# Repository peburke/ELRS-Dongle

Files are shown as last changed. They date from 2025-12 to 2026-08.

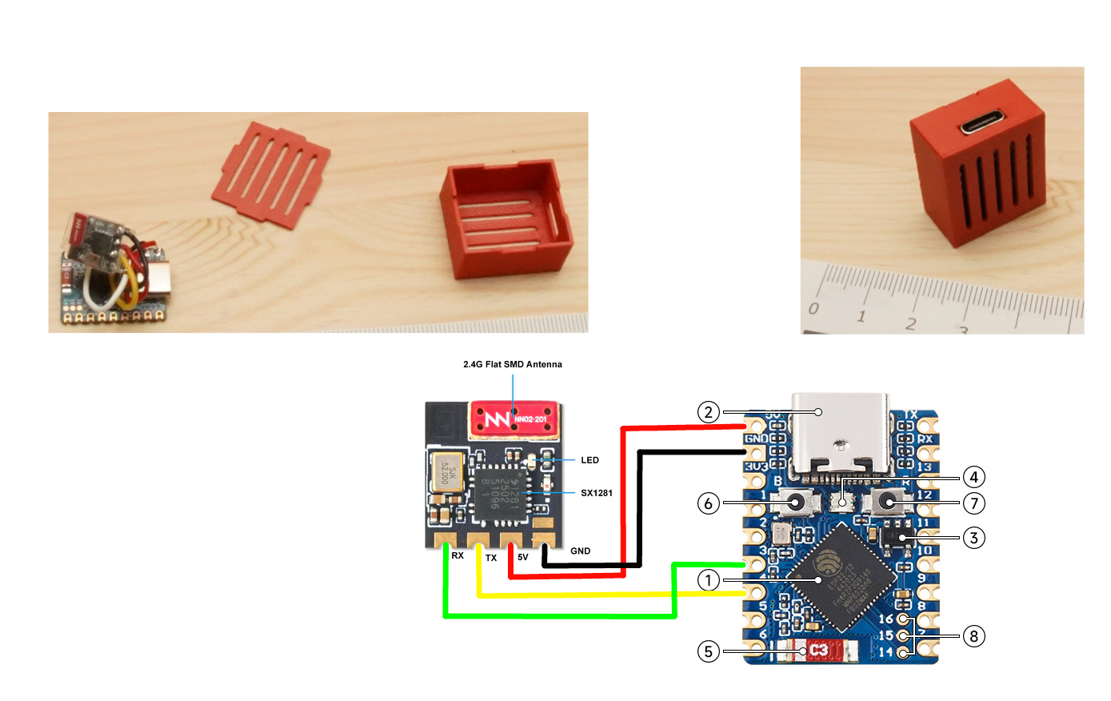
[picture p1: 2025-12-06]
Dongle.jpg

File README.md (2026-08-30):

# ELRS Dongle

An inexpensive wireless USB gamepad adapter for FPV simulators. It connects an
EdgeTX radio through an ExpressLRS transmitter and receiver to an ESP32-S3,
which presents the first four CRSF channels to a PC as joystick axes.

The dongle has been tested with Velocidrone and Liftoff. The hardware uses an
ESP32-S3-Mini and a BetaFPV ELRS Lite receiver; printable enclosure files are
included in this repository.

ELRS Dongle

See [Firmware.md](Firmware.md) for wiring, Arduino settings, calibration,
failsafe behavior, testing, and troubleshooting.

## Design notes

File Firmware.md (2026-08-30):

# ELRS Dongle Firmware

The firmware converts CRSF RC data from an ExpressLRS receiver into a native
USB HID gamepad on an ESP32-S3.

## Repository layout

| Path | Purpose |
|---|---|
| `ELRS_Dongle.ino` | ESP32-S3 hardware setup and main loop. |
| `ELRSProtocol.h/.cpp` | Testable CRSF parser, channel decoder, scaling, and failsafe state. |
| `tests/test_elrs_protocol.cpp` | Host-side protocol and behavior regression tests. |
| `.github/workflows/firmware.yml` | Native tests and an ESP32 Arduino 3.3.4 build. |
| `Body.stl`, `Top.stl`, `Dongle Case-*.3mf` | Printable enclosure files. |

## Data flow

1. UART1 reads the receiver at 420000 baud.
2. `CrsfParser` collects a frame, rejects invalid lengths and CRCs, and resets
   a stalled partial frame after 2 ms.
3. Valid type `0x16` payloads are unpacked into sixteen 11-bit channels.
4. Channels 1-4 become X, Y, throttle/Z, and Rz USB axes.
5. If no valid RC frame arrives for 1000 ms after the link has been active, a
   safe report centers roll, pitch, and yaw and lowers throttle. A rejected USB
   send is retried every 20 ms until delivery succeeds.

## Wiring

| Receiver signal | ESP32-S3 | Notes |
|---|---|---|
| TX | GPIO 3 | Required CRSF data connection. |
| RX | GPIO 4 | Reserved for future telemetry; currently unused. |
| Power and ground | Board-appropriate supply and GND | Verify the receiver voltage before wiring. |

Change `kCrsfRxPin` and `kCrsfTxPin` in `ELRS_Dongle.ino` for a different
board layout.

## Arduino configuration

- Install ESP32 Arduino core 3.3.4.
- Select an ESP32-S3 board with native USB.
- Set **USB Mode** to **USB-OTG (TinyUSB)**. `ARDUINO_USB_MODE=0` is the
  TinyUSB/OTG mode used by `USBHIDGamepad`; Hardware CDC and JTAG mode cannot
  provide this HID interface.
- Compile and upload `ELRS_Dongle.ino` together with `ELRSProtocol.h` and
  `ELRSProtocol.cpp` in a folder named `ELRS_Dongle`.

The sketch deliberately stops at compile time when native USB is unavailable
or the incompatible hardware CDC/JTAG mode is selected.

## USB controls and calibration

| CRSF channel | HID control |
|---|---|
| CH1 | X / roll |
| CH2 | Y / pitch |
| CH3 | Z / throttle |
| CH4 | Rz / yaw |

The CRSF calibration constants are minimum `172`, center `992`, and maximum
`1811`. Directional axes are scaled separately below and above center so that
center is exactly zero and both endpoints reach the HID range. Throttle maps
minimum to `-127` and maximum to `127`. Inputs outside the calibrated range
are clamped.

The unused hat is sent as `HAT_CENTER` (`0` in ESP32 core 3.3.4), and unused
buttons and axes remain released/centered.

## Link-loss behavior

CRSF receivers can stop transmitting RC channel frames during failsafe. The
firmware records each valid CRC-checked RC frame. Once a working stream has
been seen, a 1000 ms gap requests a safe USB report with centered directional
axes, minimum throttle, centered hat, and no buttons. Delivery is confirmed
only when the HID API accepts the report; a temporarily busy USB interface is
retried every 20 ms. A later valid frame automatically resumes normal reports
and rearms the timeout.

Change `kRcFailsafeTimeoutMs` if a different delay is required. Do not set it
below the expected radio update interval.

## Tests

On Windows with `g++` available:

```powershell
./tests/run_tests.ps1
```

The suite checks a hand-derived packed-channel fixture, CRC rejection,
calibrated axis endpoints, neutral HID state, one-shot link failsafe, and
parser recovery after an inter-byte timeout. GitHub Actions runs the same
tests and compiles the sketch for ESP32-S3 against core 3.3.4.

## Troubleshooting

- **No USB gamepad:** confirm the cable carries data and USB Mode is USB-OTG,
  then check that the native USB connector is being used.
- **No axis movement:** confirm the receiver is bound, set to CRSF output, and
  its TX pad is connected to GPIO 3 with a common ground.
- **Axes reversed:** reverse the corresponding transmitter output or negate
  that axis when constructing the HID report.
- **Reduced travel:** first verify transmitter output limits, then calibrate
  the controller in the simulator.

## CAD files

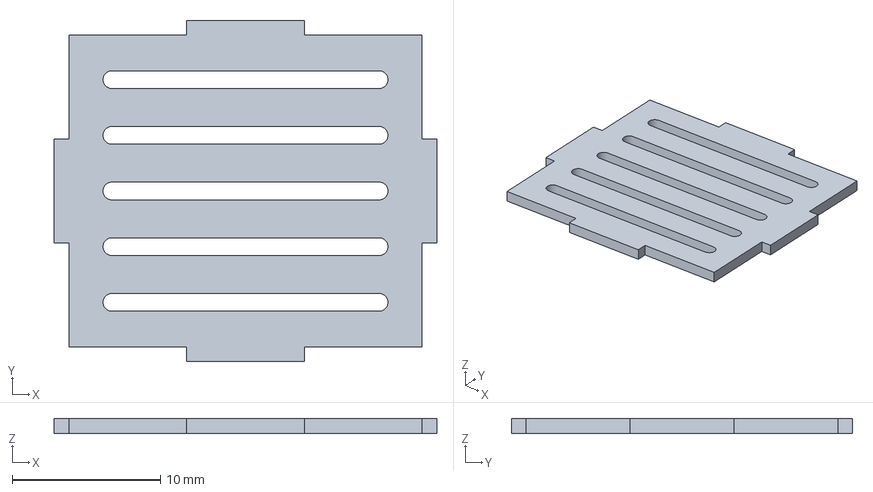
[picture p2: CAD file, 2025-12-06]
Dongle Case-Top.3mf
25.8 x 23.0 x 1.00 mm

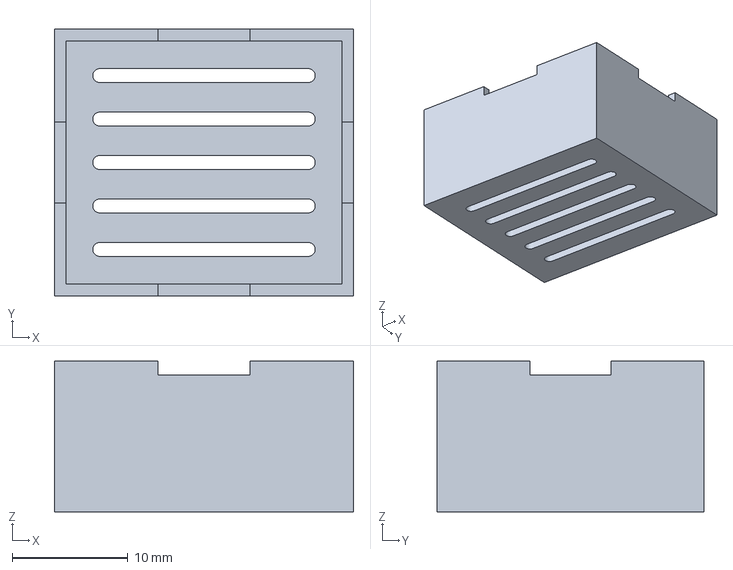
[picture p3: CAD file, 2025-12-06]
Dongle Case-Body.3mf
25.8 x 23.0 x 13.0 mm

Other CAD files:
Top.stl
Body.stl

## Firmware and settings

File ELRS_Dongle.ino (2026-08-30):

/*
 * CRSF to USB HID gamepad bridge for ESP32-S3.
 *
 * Connect the ELRS receiver TX pad to GPIO 3. GPIO 4 is reserved for
 * future CRSF telemetry and is not used by this receive-only firmware.
 */

#include <Arduino.h>

#ifndef ARDUINO_USB_MODE
#error "This firmware requires an ESP32 with native USB support."
#elif ARDUINO_USB_MODE == 1
#error "Select USB-OTG (TinyUSB), not Hardware CDC and JTAG, for USB HID."
#endif

#include <HardwareSerial.h>
#include "USB.h"
#include "USBHIDGamepad.h"

#include "ELRSProtocol.h"

static_assert(HAT_CENTER == 0, "ESP32 HID hat-center value changed");

namespace {

constexpr uint32_t kCrsfBaud = 420000;
constexpr uint8_t kCrsfUartNumber = 1;
constexpr int8_t kCrsfRxPin = 3;
constexpr int8_t kCrsfTxPin = 4;
constexpr uint32_t kParserInterByteTimeoutUs = 2000;
constexpr uint32_t kRcFailsafeTimeoutMs = 1000;
constexpr uint32_t kFailsafeRetryIntervalMs = 20;

USBHIDGamepad gamepad;
HardwareSerial crsfSerial(kCrsfUartNumber);
elrs::CrsfParser crsfParser(kParserInterByteTimeoutUs);
elrs::RcLinkState rcLink(kRcFailsafeTimeoutMs, kFailsafeRetryIntervalMs);

uint32_t hidSendFailures = 0;

bool sendHidReport(const elrs::HidReport &report) {
  if (!gamepad.send(report.x, report.y, report.z, report.rz,
                    report.rx, report.ry, report.hat, report.buttons)) {
    ++hidSendFailures;
    return false;
  }
  return true;
}

}  // namespace

void setup() {
  crsfSerial.begin(kCrsfBaud, SERIAL_8N1, kCrsfRxPin, kCrsfTxPin);

  USB.manufacturerName("ELRS Dongle");
  USB.productName("ELRS Simulator Gamepad");
  gamepad.begin();
  USB.begin();
}

void loop() {
  elrs::RcChannels channels{};

  while (crsfSerial.available() > 0) {
    const uint8_t byte = static_cast<uint8_t>(crsfSerial.read());
    if (crsfParser.push(byte, micros(), channels)) {
      rcLink.noteFrame(millis());
      sendHidReport(elrs::makeHidReport(channels));
    }
  }

  if (rcLink.shouldSendFailsafe(millis()) &&
      sendHidReport(elrs::makeFailsafeReport())) {
    rcLink.confirmFailsafeSent();
  }
}

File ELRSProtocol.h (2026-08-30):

#pragma once

#include <cstddef>
#include <cstdint>

namespace elrs {

constexpr uint8_t kSyncByte = 0xC8;
constexpr uint8_t kRcChannelsPackedType = 0x16;
constexpr std::size_t kChannelCount = 16;
constexpr std::size_t kRcPayloadLength = 22;
constexpr uint8_t kMaxFrameBodyLength = 62;

constexpr uint16_t kChannelMin = 172;
constexpr uint16_t kChannelCenter = 992;
constexpr uint16_t kChannelMax = 1811;

struct RcChannels {
  uint16_t values[kChannelCount];
};

struct HidReport {
  int8_t x;
  int8_t y;
  int8_t z;
  int8_t rz;
  int8_t rx;
  int8_t ry;
  uint8_t hat;
  uint32_t buttons;
};

uint8_t crc8(const uint8_t *data, std::size_t length);
void decodeRcChannels(const uint8_t *payload, RcChannels &channels);
int8_t mapAxis(uint16_t channel);
int8_t mapThrottle(uint16_t channel);
HidReport makeHidReport(const RcChannels &channels);
HidReport makeFailsafeReport();

class CrsfParser {
 public:
  explicit CrsfParser(uint32_t interByteTimeoutUs = 2000);
  bool push(uint8_t byte, uint32_t nowUs, RcChannels &channels);
  void reset();

 private:
  enum class State : uint8_t { WaitSync, WaitLength, ReadBody };

  State state_;
  uint8_t expectedLength_;
  uint8_t index_;
  uint8_t body_[kMaxFrameBodyLength];
  uint32_t interByteTimeoutUs_;
  uint32_t lastByteUs_;
};

class RcLinkState {
 public:
  explicit RcLinkState(uint32_t timeoutMs, uint32_t retryIntervalMs = 20);
  void noteFrame(uint32_t nowMs);
  bool shouldSendFailsafe(uint32_t nowMs);
  void confirmFailsafeSent();

 private:
  uint32_t timeoutMs_;
  uint32_t retryIntervalMs_;
  uint32_t lastFrameMs_;
  uint32_t lastAttemptMs_;
  bool hasFrame_;
  bool hasAttempted_;
  bool failsafeSent_;
};

}  // namespace elrs

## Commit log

2025-12-06 Add files via upload
    Arduino sketch
2026-08-29 Fix CRSF input safety and USB HID behavior
    [ELRSProtocol.h, ELRS_Dongle.ino]
2026-08-29 Retry failsafe reports until USB delivery succeeds
    [ELRSProtocol.h, ELRS_Dongle.ino]
